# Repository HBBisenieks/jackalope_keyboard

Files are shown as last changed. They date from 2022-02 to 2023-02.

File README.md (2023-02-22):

# Jackalope Keyboard


`NOTE:` Current source was built against `ergogen@3.1.1` and will not work with the `4.0.0` release (or newer).

A 50-key ergonomic ~(currently single-piece)~ single-piece or split column-staggered keyboard ~(with a split version planned for the future???)~ inspired by the Absolem, Kryia, and Iris.

The Jackalope layout is focussed on maximizing comfort for the thumbs and reducing reach for the fingers.

## To-Do:
- [x] Finalize prototype PCBs
- [ ] Verify PCBs
- [ ] BOM and build guide
- [ ] Default firmware

## Firmware
The Jackalope can run either [QMK](https://github.com/HBBisenieks/qmk_firmware/tree/jackalope_boards/keyboards/jackalope) 
with a pro-micro or KMK with a KB2040. Default keymap is still a work-in-progress pending 
actual hardware testing.

## Images
Renders of the left and right split PCBs:

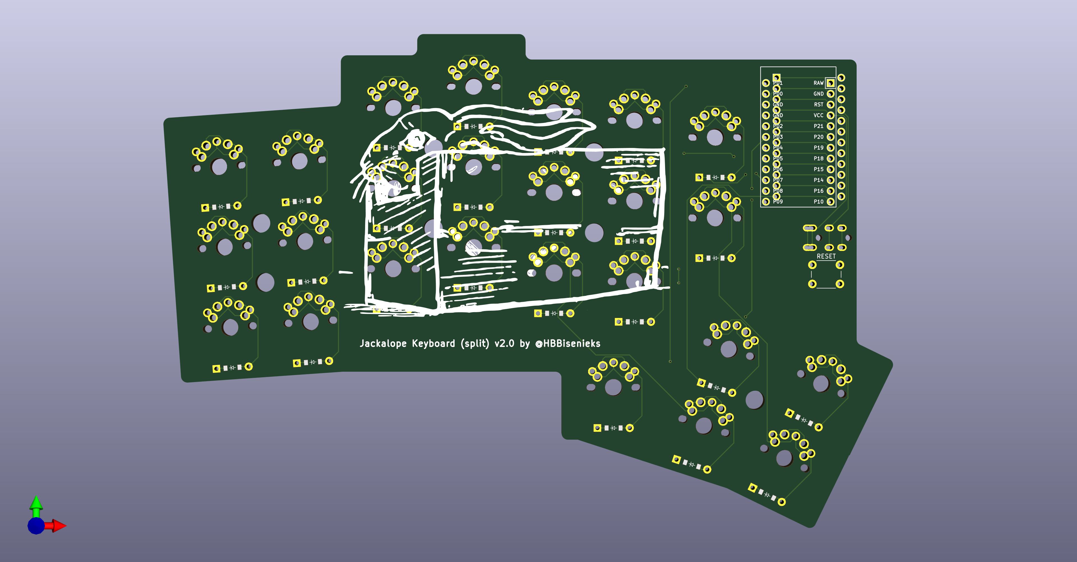
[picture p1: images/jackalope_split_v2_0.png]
3D render of a split keyboard PCB. The board is shaped vaguely like the state of Vermont on its side. There is a drawing of a rabbit in a box printed on the board.


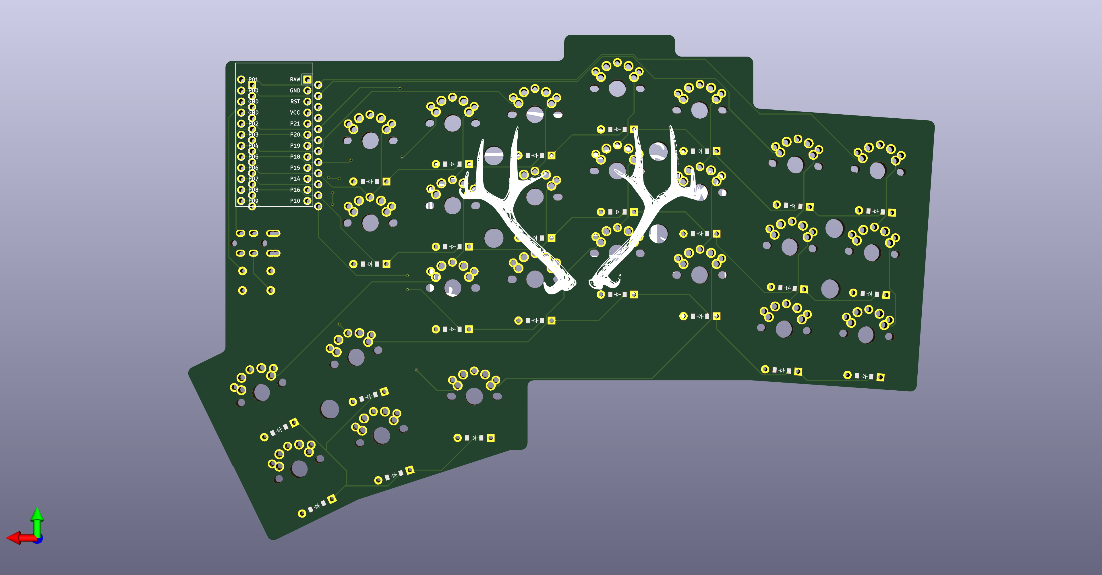
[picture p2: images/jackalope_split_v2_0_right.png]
3D render of a split keyboard PCB. The board is shaped vaguely like the state of New Hampshire on its side. There is a drawing of a pair of antlers printed on the board.


## Old images of first-generation monoblock PCB and layout
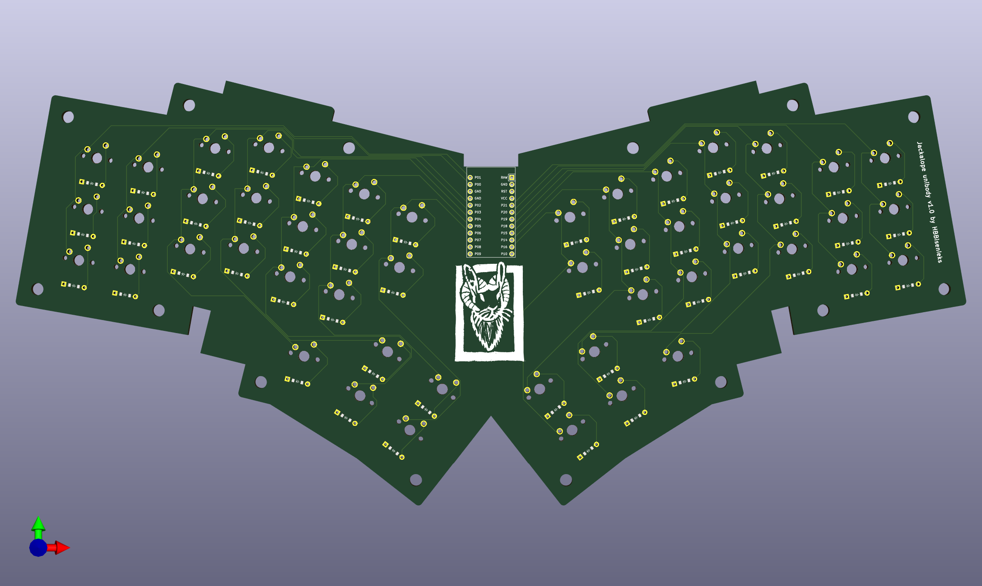
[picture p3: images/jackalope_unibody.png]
3D render of a keyboard pcb. The board is vaguely bat-shaped and has 6 columns of 3 keys plus and inner column of 2 keys above a 5-key thumb cluster on either side of the board, with space for a microcontroller in the center


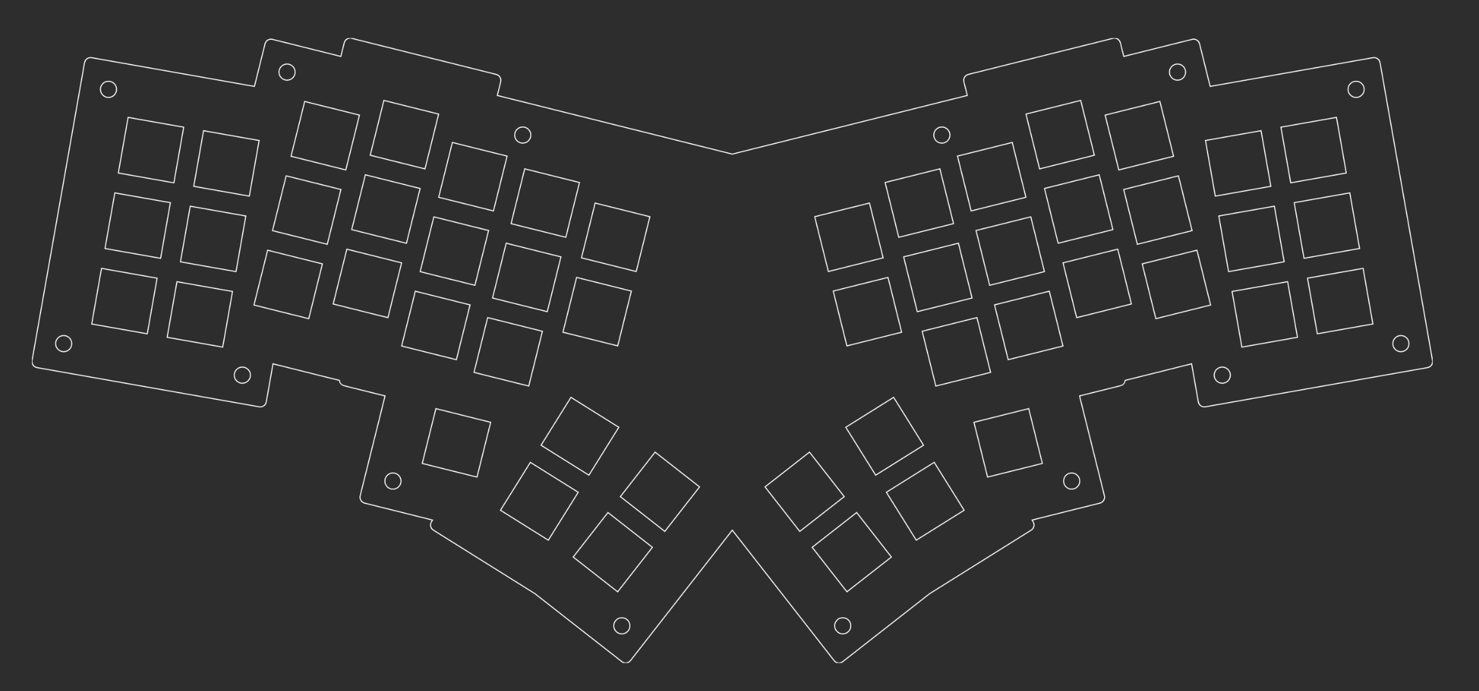
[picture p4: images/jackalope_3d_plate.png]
Image of v0.1 plate with screw holes for a 3d-printed case


Built using [Ergogen](https://ergogen.xyz/#).

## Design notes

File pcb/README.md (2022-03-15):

# PCBs
The current revision of the boards, both split and monoblock, are under `v2_0/`. As previously, 
these boards are theoretically functional but untested, pending both firmware authoring (QMK and 
KMK support planned) and arrival of the prototype boards from JLCPCB.

## To-Do:
- [ ] Write QMK code
- [ ] Write KMK code
- [ ] Verify PCBs
- [ ] Build guide
- [ ] BOM

~The current revision of PCB uploaded to GH is routed but untested and reflects an older revision of the code than what's available in the base of the repo. It _might_ work, but I honestly put it together to learn a bit more about using KiCad than anything else and haven't yet tested the outline, so, you know, caveat emptor.~

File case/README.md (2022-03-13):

# Cases

`minimal` case files are just slightly larger than the associated PCB and are mounted with internal screws and
spacers. Other plates can be mounted using internal or external screws and spacers.

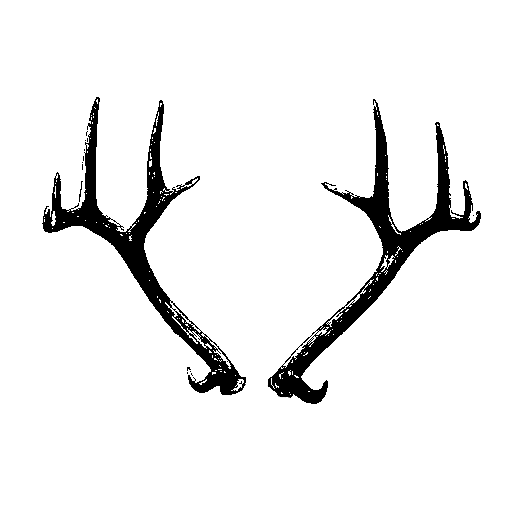
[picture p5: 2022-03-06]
images/antlers.png

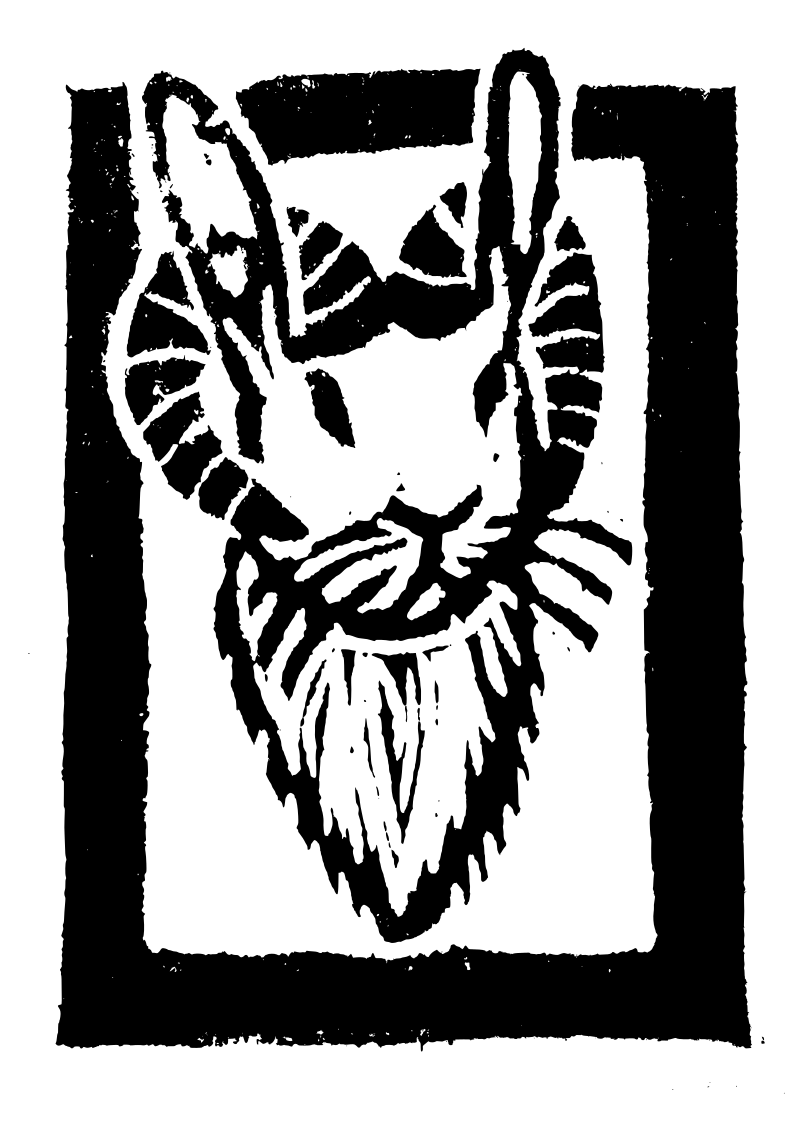
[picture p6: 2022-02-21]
images/bighorn.png

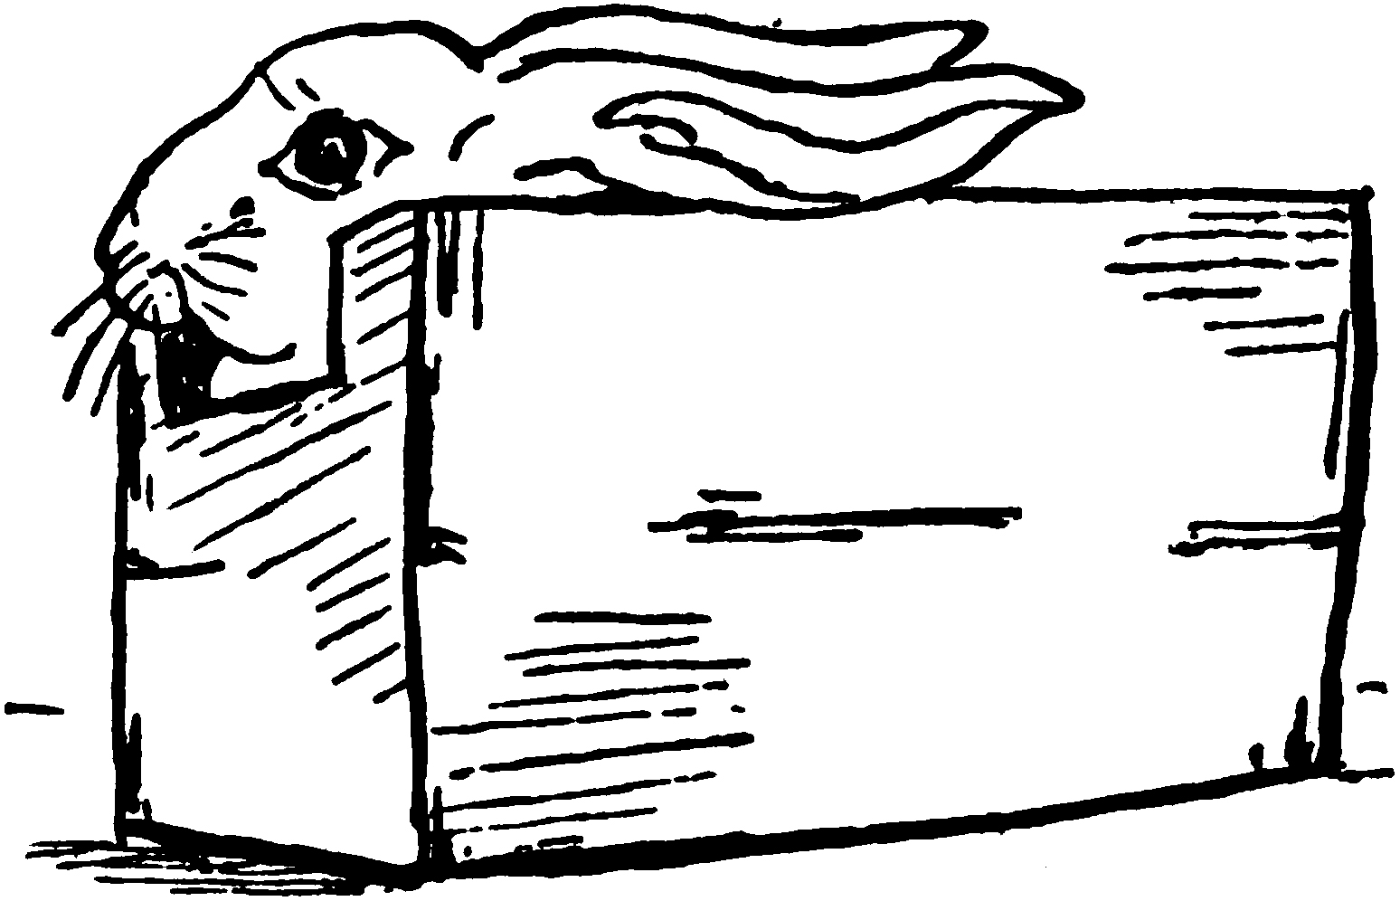
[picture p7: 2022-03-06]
images/rabbit.png

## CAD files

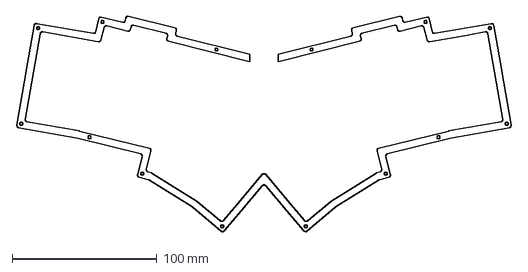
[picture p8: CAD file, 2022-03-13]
case/jackalope_1p_middle.dxf
341.9 x 149.0 mm

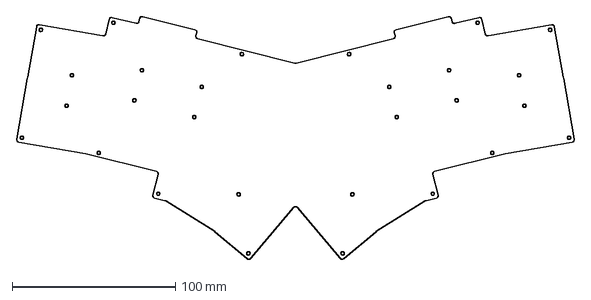
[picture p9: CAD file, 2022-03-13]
case/jackalope_1p_bottom.dxf
341.9 x 149.0 mm

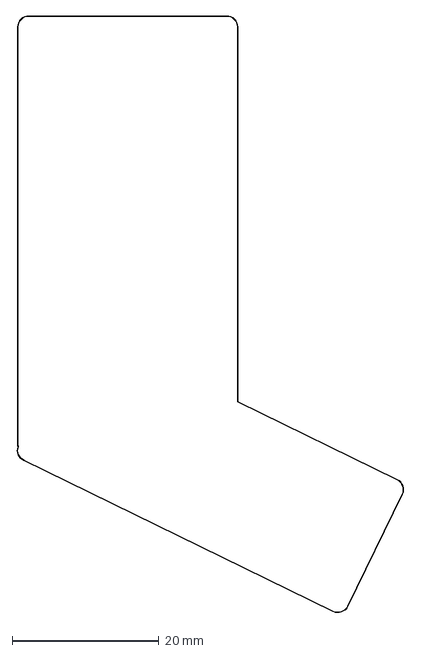
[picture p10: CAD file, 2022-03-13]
case/split_controller_plate_cutout.dxf
53.1 x 81.6 mm

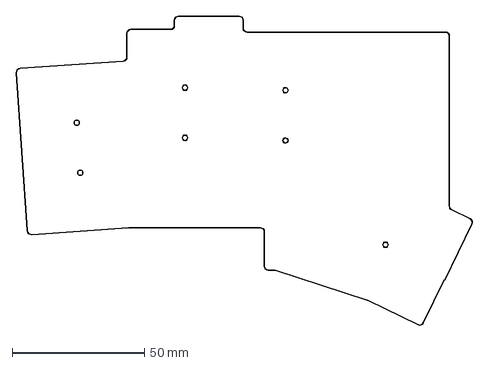
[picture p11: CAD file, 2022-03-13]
case/jackalope_minimal_split_bottom.dxf
172.7 x 117.1 mm

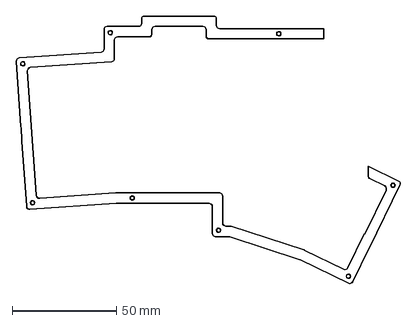
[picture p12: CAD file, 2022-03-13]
case/jackalope_split_middle.dxf
184.8 x 128.8 mm

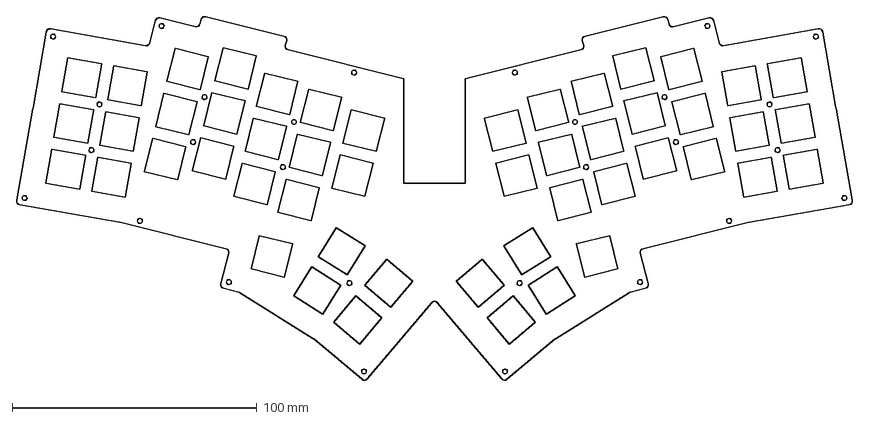
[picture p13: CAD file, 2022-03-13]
case/jackalope_1p_plate.dxf
341.9 x 149.0 mm

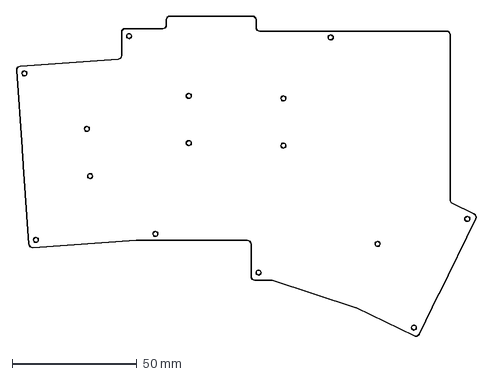
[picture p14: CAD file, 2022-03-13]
case/jackalope_split_bottom.dxf
184.8 x 128.8 mm

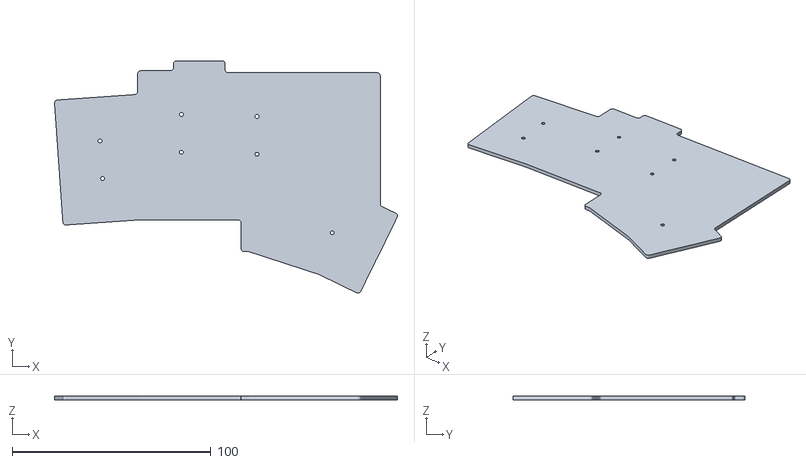
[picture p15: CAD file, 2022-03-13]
case/split_case_minimal_bottom_3d.stl
172.5 x 116.9 x 2.00

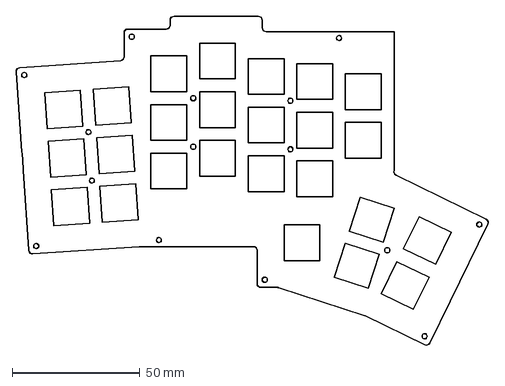
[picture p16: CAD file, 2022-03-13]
case/jackalope_split_plate.dxf
184.8 x 128.8 mm

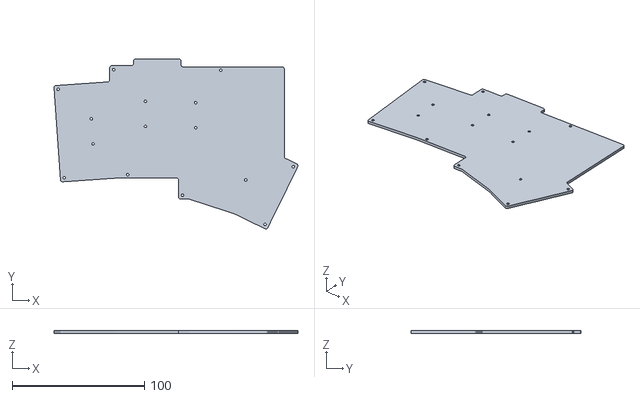
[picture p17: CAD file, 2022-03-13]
case/split_case_bottom.stl
184.5 x 128.5 x 2.00

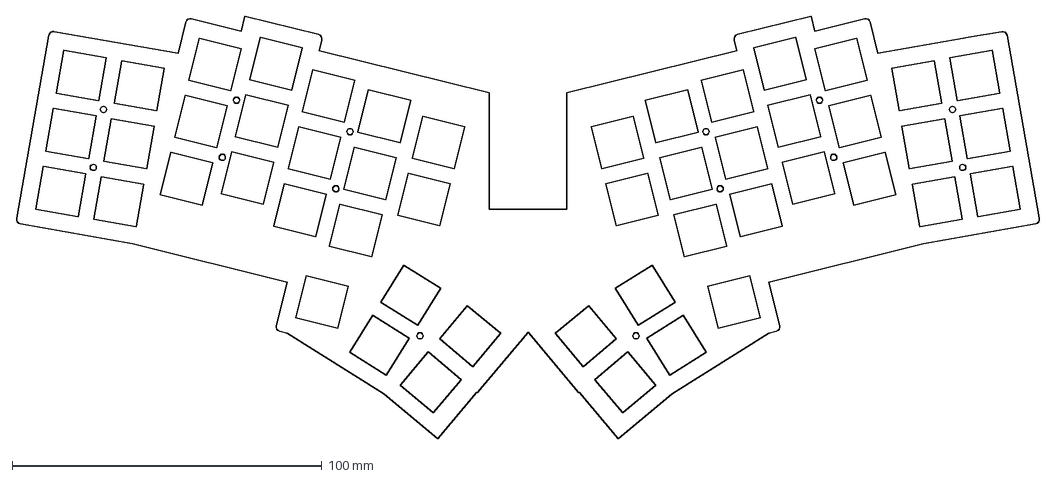
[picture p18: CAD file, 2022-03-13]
case/jackalope_1p_minimal_plate.dxf
330.3 x 136.5 mm

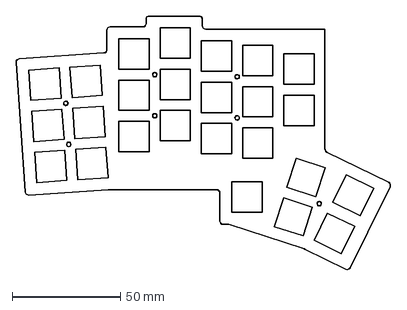
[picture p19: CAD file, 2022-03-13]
case/jackalope_minimal_split_plate.dxf
172.7 x 117.1 mm

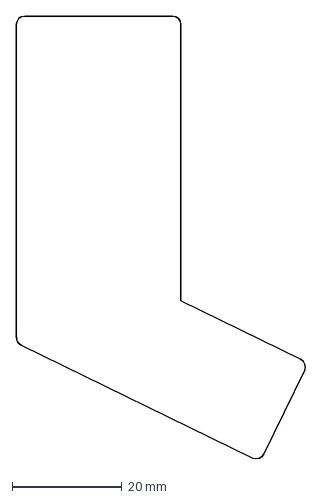
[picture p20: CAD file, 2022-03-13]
case/split_controller_minimal_plate_cutout.dxf
52.9 x 81.0 mm

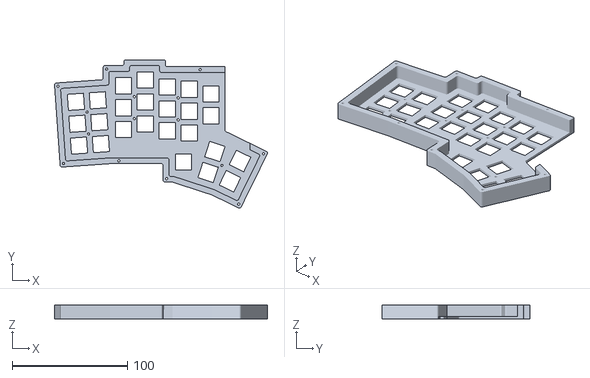
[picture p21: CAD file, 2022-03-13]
case/split_case_top.stl
184.5 x 128.5 x 12.0

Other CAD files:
case/jackalope_1p_minimal_bottom.dxf
case/split_case_minimal_plate_3d.stl

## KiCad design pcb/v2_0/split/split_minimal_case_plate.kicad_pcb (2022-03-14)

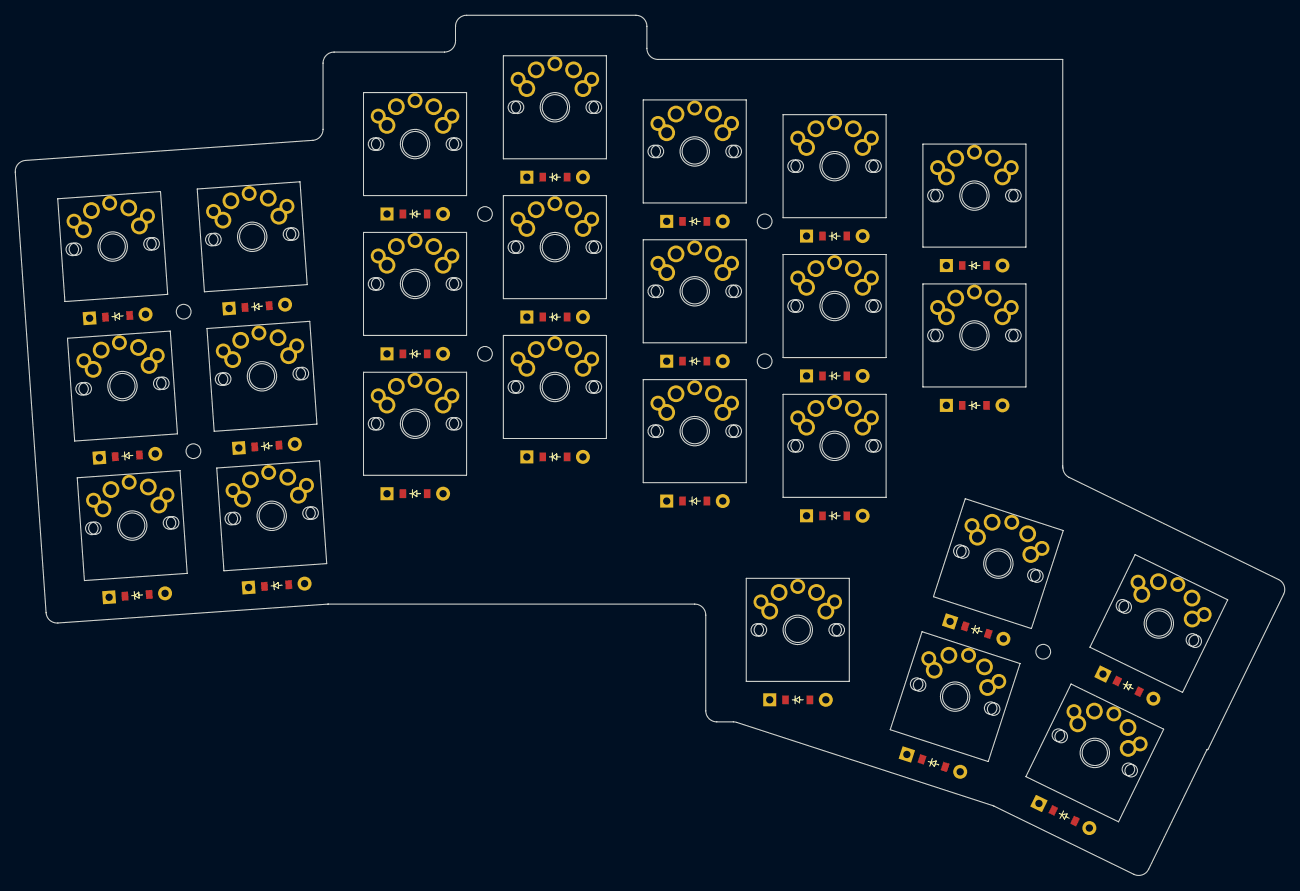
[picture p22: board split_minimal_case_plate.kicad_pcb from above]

Board: 2 copper layers, 172.5 x 116.9 mm, 75 parts (0 on the bottom side), 36 nets, no tracks yet.

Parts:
D1, D2, D3, D4, D5, D6, D7, D8, D9, D10, D11, D12, D13, D14, D15, D16, D17, D18, D19, D20, D21, D22, D23, D24, D25: ComboDiode
S1, S3, S5, S7, S9, S11, S13, S15, S17, S19, S21, S23, S25, S27, S29, S31, S33, S35, S37, S39, S41, S43, S45, S47, S49: MX
S2, S4, S6, S8, S10, S12, S14, S16, S18, S20, S22, S24, S26, S28, S30, S32, S34, S36, S38, S40, S42, S44, S46, S48, S50: PG1350

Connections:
P0: S7.2, S8.2, S9.2, S10.2, S11.2, S12.2
P1: S1.2, S2.2, S3.2, S4.2, S5.2, S6.2
P2: S13.2, S14.2, S15.2, S16.2, S17.2, S18.2, S41.2, S42.2
P3: S19.2, S20.2, S21.2, S22.2, S23.2, S24.2, S43.2, S44.2
P4: S25.2, S26.2, S27.2, S28.2, S29.2, S30.2, S47.2, S48.2
P5: S31.2, S32.2, S33.2, S34.2, S35.2, S36.2, S45.2, S46.2
P6: S37.2, S38.2, S39.2, S40.2, S49.2, S50.2
P7: D3.1, D3.2, D6.1, D6.2, D9.1, D9.2, D12.1, D12.2, D15.1, D15.2, D18.1, D18.2, D20.1, D20.2
P8: D2.1, D2.2, D5.1, D5.2, D8.1, D8.2, D11.1, D11.2, D14.1, D14.2, D17.1, D17.2, D19.1, D19.2
P9: D1.1, D1.2, D4.1, D4.2, D7.1, D7.2, D10.1, D10.2, D13.1, D13.2, D16.1, D16.2
P10: D21.1, D21.2, D22.1, D22.2, D23.1, D23.2, D24.1, D24.2, D25.1, D25.2
home_lower: D24.1, D24.2, S47.1, S48.1
home_upper: D22.1, D22.2, S43.1, S44.1
index_bottom: D13.1, D13.2, S25.1, S26.1
index_home: D14.1, D14.2, S27.1, S28.1
index_top: D15.1, D15.2, S29.1, S30.1
inner_bottom: D16.1, D16.2, S31.1, S32.1
inner_home: D17.1, D17.2, S33.1, S34.1
inner_top: D18.1, D18.2, S35.1, S36.1
inner_upper: D21.1, D21.2, S41.1, S42.1
macro_home: D19.1, D19.2, S37.1, S38.1
macro_top: D20.1, D20.2, S39.1, S40.1
middle_bottom: D10.1, D10.2, S19.1, S20.1
middle_home: D11.1, D11.2, S21.1, S22.1
middle_top: D12.1, D12.2, S23.1, S24.1
outer_bottom: D1.1, D1.2, S1.1, S2.1
outer_home: D2.1, D2.2, S3.1, S4.1
outer_lower: D25.1, D25.2, S49.1, S50.1
outer_top: D3.1, D3.2, S5.1, S6.1
outer_upper: D23.1, D23.2, S45.1, S46.1
pinky_bottom: D4.1, D4.2, S7.1, S8.1
pinky_home: D5.1, D5.2, S9.1, S10.1
pinky_top: D6.1, D6.2, S11.1, S12.1
ring_bottom: D7.1, D7.2, S13.1, S14.1
ring_home: D8.1, D8.2, S15.1, S16.1
ring_top: D9.1, D9.2, S17.1, S18.1

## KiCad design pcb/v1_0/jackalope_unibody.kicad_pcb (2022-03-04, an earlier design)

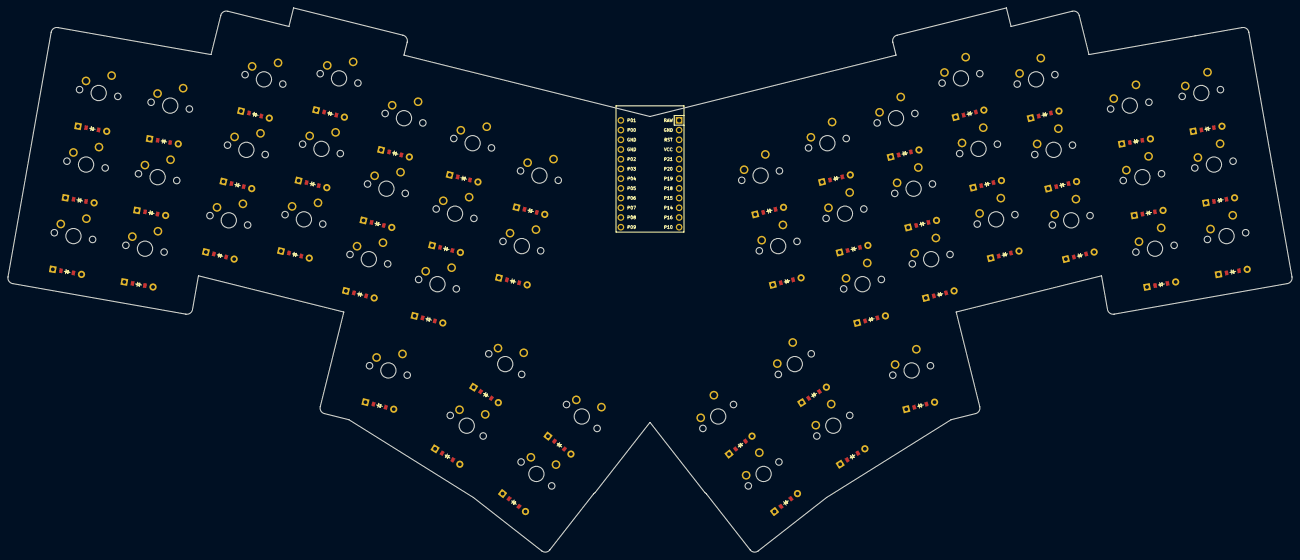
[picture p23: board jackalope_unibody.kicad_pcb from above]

Board: 2 copper layers, 335.9 x 142.3 mm, 101 parts (0 on the bottom side), 69 nets, no tracks yet.

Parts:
D1, D2, D3, D4, D5, D6, D7, D8, D9, D10, D11, D12, D13, D14, D15, D16, D17, D18, D19, D20, D21, D22, D23, D24, D25, D26, D27, D28, D29, D30, D31, D32, D33, D34, D35, D36, D37, D38, D39, D40, D41, D42, D43, D44, D45, D46, D47, D48, D49, D50: ComboDiode
MCU1: ProMicro
S1, S2, S3, S4, S5, S6, S7, S8, S9, S10, S11, S12, S13, S14, S15, S16, S17, S18, S19, S20, S21, S22, S23, S24, S25, S26, S27, S28, S29, S30, S31, S32, S33, S34, S35, S36, S37, S38, S39, S40, S41, S42, S43, S44, S45, S46, S47, S48, S49, S50: MX

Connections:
GND: MCU1.2, MCU1.15, MCU1.16
P0: MCU1.14, S4.2, S5.2, S6.2
P1: MCU1.13, S1.2, S2.2, S3.2
P2: MCU1.17, S7.2, S8.2, S9.2, S21.2
P3: MCU1.18, S10.2, S11.2, S12.2, S22.2
P4: MCU1.19, S13.2, S14.2, S15.2, S24.2
P5: MCU1.20, S16.2, S17.2, S18.2, S23.2
P6: MCU1.21, S19.2, S20.2, S25.2
P7: D3.1, D3.2, D6.1, D6.2, D9.1, D9.2, D12.1, D12.2, D15.1, D15.2, D18.1, D18.2, D20.1, D20.2, D28.1, D28.2, D31.1, D31.2, D34.1, D34.2, D37.1, D37.2, D40.1, D40.2, D43.1, D43.2, D45.1, D45.2, MCU1.22
P8: D2.1, D2.2, D5.1, D5.2, D8.1, D8.2, D11.1, D11.2, D14.1, D14.2, D17.1, D17.2, D19.1, D19.2, D27.1, D27.2, D30.1, D30.2, D33.1, D33.2, D36.1, D36.2, D39.1, D39.2, D42.1, D42.2, D44.1, D44.2, MCU1.23
P9: D1.1, D1.2, D4.1, D4.2, D7.1, D7.2, D10.1, D10.2, D13.1, D13.2, D16.1, D16.2, D26.1, D26.2, D29.1, D29.2, D32.1, D32.2, D35.1, D35.2, D38.1, D38.2, D41.1, D41.2, MCU1.24
P10: D21.1, D21.2, D22.1, D22.2, D23.1, D23.2, D24.1, D24.2, D25.1, D25.2, D46.1, D46.2, D47.1, D47.2, D48.1, D48.2, D49.1, D49.2, D50.1, D50.2, MCU1.12
P14: MCU1.10, S41.2, S42.2, S43.2, S48.2
P15: MCU1.9, S38.2, S39.2, S40.2, S49.2
P16: MCU1.11, S44.2, S45.2, S50.2
P18: MCU1.8, S35.2, S36.2, S37.2, S47.2
P19: MCU1.7, S32.2, S33.2, S34.2, S46.2
P20: MCU1.6, S29.2, S30.2, S31.2
P21: MCU1.5, S26.2, S27.2, S28.2
home_lower: D24.1, D24.2, S24.1
home_upper: D22.1, D22.2, S22.1
index_bottom: D13.1, D13.2, S13.1
index_home: D14.1, D14.2, S14.1
index_top: D15.1, D15.2, S15.1
inner_bottom: D16.1, D16.2, S16.1
inner_home: D17.1, D17.2, S17.1
inner_top: D18.1, D18.2, S18.1
inner_upper: D21.1, D21.2, S21.1
macro_home: D19.1, D19.2, S19.1
macro_top: D20.1, D20.2, S20.1
middle_bottom: D10.1, D10.2, S10.1
middle_home: D11.1, D11.2, S11.1
middle_top: D12.1, D12.2, S12.1
mirror_home_lower: D49.1, D49.2, S49.1
mirror_home_upper: D47.1, D47.2, S47.1
mirror_index_bottom: D38.1, D38.2, S38.1
mirror_index_home: D39.1, D39.2, S39.1
mirror_index_top: D40.1, D40.2, S40.1
mirror_inner_bottom: D41.1, D41.2, S41.1
mirror_inner_home: D42.1, D42.2, S42.1
mirror_inner_top: D43.1, D43.2, S43.1
mirror_inner_upper: D46.1, D46.2, S46.1
mirror_macro_home: D44.1, D44.2, S44.1
mirror_macro_top: D45.1, D45.2, S45.1
mirror_middle_bottom: D35.1, D35.2, S35.1
mirror_middle_home: D36.1, D36.2, S36.1
mirror_middle_top: D37.1, D37.2, S37.1
mirror_outer_bottom: D26.1, D26.2, S26.1
mirror_outer_home: D27.1, D27.2, S27.1
mirror_outer_lower: D50.1, D50.2, S50.1
mirror_outer_top: D28.1, D28.2, S28.1
mirror_outer_upper: D48.1, D48.2, S48.1
mirror_pinky_bottom: D29.1, D29.2, S29.1
mirror_pinky_home: D30.1, D30.2, S30.1
mirror_pinky_top: D31.1, D31.2, S31.1
mirror_ring_bottom: D32.1, D32.2, S32.1
mirror_ring_home: D33.1, D33.2, S33.1
mirror_ring_top: D34.1, D34.2, S34.1
outer_bottom: D1.1, D1.2, S1.1
outer_home: D2.1, D2.2, S2.1
outer_lower: D25.1, D25.2, S25.1
outer_top: D3.1, D3.2, S3.1
outer_upper: D23.1, D23.2, S23.1
pinky_bottom: D4.1, D4.2, S4.1
pinky_home: D5.1, D5.2, S5.1
pinky_top: D6.1, D6.2, S6.1
ring_bottom: D7.1, D7.2, S7.1
ring_home: D8.1, D8.2, S8.1
ring_top: D9.1, D9.2, S9.1

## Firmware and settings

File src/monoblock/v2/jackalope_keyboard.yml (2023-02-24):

points:
  zones:
    matrix:
      anchor:
        rotate: 5
      columns:
        outer:
          key:
            column_net: P1
            mirror:
              column_net: P1
          rows:
            bottom:
              bind: [5, 5, 0, 0]
            home:
              bind: [5, 5, 5, 0]
            top:
              bind: [0, 5, 5, 0]
        pinky:
          key:
            column_net: P0
            mirror:
              column_net: P0
          rows:
            bottom:
              bind: [5, 0, 0, 5]
            home:
              bind: [5, 5, 5, 5]
            top:
              bind: [0, 15, 5, 5]
        ring:
          key:
            column_net: P4
            mirror:
              column_net: P4
          rotate: -4
          origin: [-12, -19]
          stagger: 12
          rows:
            bottom:
              bind: [5, 5, 12, 5]
            home:
              bind: [5, 5, 5, 5]
            top:
              bind: [0, 5, 5, 0]
        middle:
          key:
            column_net: P5
            mirror:
              column_net: P5
          stagger: 5
          rows:
            bottom:
              bind: [5, 5, 17, 5]
            home:
              bind: [5, 5, 5, 5]
            top:
              bind: [0, 0, 5, 1]
        index:
          key:
            column_net: P6
            mirror:
              column_net: P6
          stagger: -6
          rows:
            bottom:
              bind: [5, 5, 11, 5]
            home:
              bind: [5, 5, 5, 5]
            top:
              bind: [0, 5, 5, 5]
        inner:
          key:
            column_net: P7
            mirror:
              column_net: P7
          stagger: -2
          rows:
            bottom:
              bind: [15, 40, 15, 5]
            home:
              bind: [5, 40, 5, 5]
            top:
              bind: [2, 40, 5, 5]
        macro:
          row_overrides:
            home:
            top:
          key:
            column_net: P8
            mirror:
              column_net: P8  
          stagger: 15
          rows:
            home:
              bind: [5, 0, 15, 5]
            top:
              bind: [0, 0, 5, 5]
      rows:
        bottom:
          bind: 10
          row_net: P16
          mirror:
            row_net: P18
        home:
          bind: 10
          row_net: P10
          mirror:
            row_net: P19
        top:
          bind: 5
          row_net: P9
          mirror:
            row_net: P20
    t_upper:
      anchor:
        ref: matrix_inner_bottom
        shift: [-5, -25]
      columns:
        inner:
          key:
            column_net: P1
            mirror:
              column_net: P1
          rows:
            upper:
              bind: [15, 15, 0, 0]
        home:
          key:
            column_net: P0
            mirror:
              column_net: P0
          rows:
            upper:
              bind: [0, 3, 0, 15]
          stagger: 9
          spread: 27.25
          rotate: -18
        outer:
          key:
            column_net: P4
            mirror:
              column_net: P4
          rows:
            upper:
              bind: [3, 1, 0, 3]
          stagger: -1
          spread: 23.25
          rotate: -8
      rows:
        upper:
          bind: 10
          row_net: P14
          mirror:
            row_net: P15
    t_lower:
      anchor:
        ref: t_upper_home_upper
        shift: [0, -19]
      columns:
        home:
          key:
            column_net: P5
          rows:
            lower:
              bind: [5, 5, 0, 15]
        outer:
          key:
            column_net: P6
          rows:
            lower:
              bind: [5, 1, 0, 3]
          spread: 19.25
          rotate: -8
          origin: [-9.5, -9]
      rows:
        lower:
          bind: [5, 0, 0, 0]
          row_net: P14
          mirror:
            row_net: P15
  key:
    footprints:
      mx:
        type: mx
        nets:
          from: =colrow
          to: =column_net
      choc:
        type: choc
        nets:
          from: =colrow
          to: =column_net
      diode:
        type: diode
        nets:
          from: =colrow
          to: =row_net
        anchor:
          shift: [0, -9.5]
  rotate: -15
  mirror:
    ref: matrix_outer_home
    distance: 295
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

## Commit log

2022-02-18 added filler shapes for case
2022-02-18 fix top plates
2022-02-18 change to exterior mounting holes only
2022-02-19 fixed bind outline fuckery
    [jackalope_keyboard.yml]
2022-02-19 move diodes down
2022-02-20 replacing thumb cluster 2-row with single row for pcb
2022-02-20 replaced thumb cluster, need to fix binds
    [jackalope_keyboard.yml]
2022-02-21 fixed outline, thumb screwhole
    [jackalope_keyboard.yml]
2022-02-21 initial pcb commit
    [jackalope_unibody.dsn, jackalope_unibody.kicad_pcb]
2022-02-21 pcb getting prettier
    [jackalope_unibody.kicad_pcb]
2022-02-24 begin split work, spelling mistake fixed, gerbers
    [jackalope_unibody.kicad_pcb]
2022-02-24 screw holes for split
2022-02-25 refining pcb shape
2022-02-25 update screw holes for 1p
2022-02-25 refining case shape for split
2022-02-25 move top screw hole
2022-02-27 fixing screw holes
2022-02-27 more screw-hole stuff idek
2022-02-28 update split middle, extrude split case
2022-02-28 first case commit
    [split_case_bottom.stl, split_case_top.stl]
2022-02-28 PCB readme
2022-02-28 add controller cutout for 1p middle, move 1p inner top screw holes
2022-03-03 shrink pcb, some tweaks, still incomplete
2022-03-03 fixed gap in outline
    [jackalope_keyboard.yml]
2022-03-03 cleanup of pcb directory
    [jackalope_unibody.dsn, jackalope_unibody.kicad_pcb]
2022-03-04 pre-merge pcb
    [jackalope_unibody-B_Cu.gbr, jackalope_unibody-B_Mask.gbr, jackalope_unibody-B_Paste.gbr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]
2022-03-04 de-1p-ing split code, not tested at all yet
2022-03-04 de-split code. untested but should work
2022-03-05 re-de-splitting 1p
2022-03-06 updates to split board....again
2022-03-06 de-rotate, fix screw holes, add choc footprints, trrs, mcu
    [jackalope_split.yml]
2022-03-06 footprints for new silks
2022-03-07 add inner mounting holes
2022-03-07 add minimal plates, inner mounting holes
2022-03-07 minimal case plates
2022-03-07 initial commit of split pcb v2.0
    [jackalope_split.dsn, jackalope_split.kicad_pcb, minimal_case_bottom.kicad_pcb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]
2022-03-13 add inner mounting holes, minimal cases
2022-03-13 screwed up a screw hole
2022-03-13 add inner screw holes to cases
2022-03-13 routed split board, but screw holes screwed up
    [jackalope_split.kicad_pcb]
2022-03-13 case files
    [jackalope_1p_bottom.dxf, jackalope_1p_middle.dxf, jackalope_1p_minimal_bottom.dxf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]
2022-03-13 1p pcb files
    [jackalope_unibody-B_Cu.gbr, jackalope_unibody-B_Mask.gbr, jackalope_unibody-B_Paste.gbr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]
2022-03-13 update silks
    [jackalope_unibody-B_Cu.gbr, jackalope_unibody-B_Mask.gbr, jackalope_unibody-B_Paste.gbr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]
2022-03-13 update pcb file
    [jackalope_unibody.kicad_pcb]
2022-03-14 updates to 1p pcb, gerbers
    [jackalope_unibody-B_Cu.gbr, jackalope_unibody-B_Mask.gbr, jackalope_unibody-B_Paste.gbr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]
2022-03-14 split pcb routed, gerbers
    [jackalope_split-B_Cu.gbr, jackalope_split-B_Mask.gbr, jackalope_split-B_Paste.gbr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]
2022-03-14 update pcb readme
2023-02-24 added tray case
2023-02-24 revised wiring, added OLED pads
